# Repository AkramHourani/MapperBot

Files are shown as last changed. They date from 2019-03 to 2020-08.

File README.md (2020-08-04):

# MapperBot / iSCAN: 
SLAM Robot and Algorithm based on Matlab and Arduino

Robot name: MapperBot  
Algorithm name: iSCAN  

Video link to the robot: https://www.youtube.com/watch?v=dXMMgDs58lA

For detailed infromaiton about the SLAM algorithms based on particel filter:
Al-Hourani, A., Ristic, B. MapperBot/iSCAN: open-source integrated robotic platform and algorithm for 2D mapping. Int J Intell Robot Appl 4, 44–56 (2020). https://doi.org/10.1007/s41315-020-00118-3

# iSCAN Algorithm
For details please read the full paper describing the algorithm and the robot’s function.  
The project indludes three sample LIDAR row data collected using MapperBot, to run the demo: **\iSCAN\main.m**  
You can try the different measurements by uncommenting the relevant file inside: \iSCAN\main.m  
You can change the algorithm parameters under in the file: \iSCAN\Parameters.m

# MapperBot
The source files for the Arduino are inside the folder: \ArduinoSourceCode  
Hardware layout and photo inside the folder: \HardwareDesign
The file: \Robot Control\A01_MapperBot_Mouse.m will allow you to control MapperBot using a mouse from Matlab environment.

The project is created/developed by Dr Akram Al-Hourani (2019)  
Condition of use: please cite the paper

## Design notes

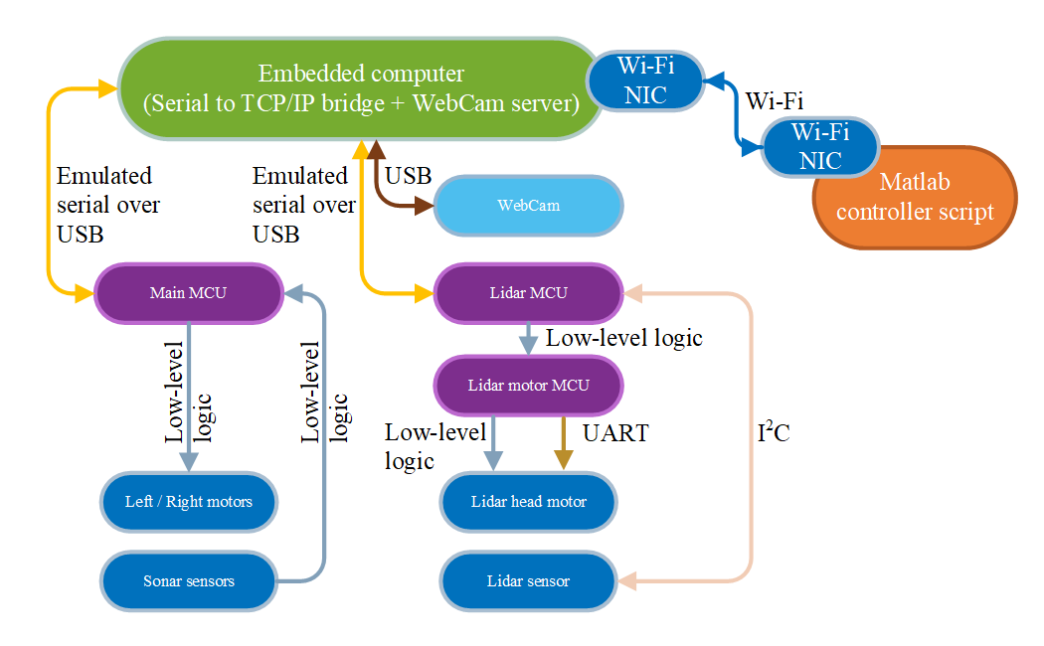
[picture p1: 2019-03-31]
HardwareDesign/HarwareDiagram.png

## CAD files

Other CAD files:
CAD Designs/Alignment_Tong.ipt
CAD Designs/ArduinoDue.ipt
CAD Designs/Battery.ipt
CAD Designs/BatteryCover.ipt
CAD Designs/Bearing.ipt
CAD Designs/Belt.ipt
CAD Designs/Cover.ipt
CAD Designs/HeadStepper.ipt
CAD Designs/LIDAR.ipt
CAD Designs/LIDARHolder.ipt
CAD Designs/LIDARLite.ipt
CAD Designs/LIDARNeck.ipt
CAD Designs/Logic Reg.ipt
CAD Designs/Main Body.ipt
CAD Designs/MapperBot2.iam
CAD Designs/MotorClamp.ipt
CAD Designs/MotorReg.ipt
CAD Designs/RaspberryPi.ipt
CAD Designs/Sonar.ipt
CAD Designs/StepperMotor.ipt
CAD Designs/WheelCore.ipt
CAD Designs/WheelRubber.ipt

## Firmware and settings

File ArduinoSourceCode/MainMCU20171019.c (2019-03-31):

#include <AccelStepper.h> // library of the stepper motor
#include <MultiStepper.h>   // For coordinated movments

#define motorPin_L_En   48 // Enable Pin
#define motorPin_L_Dir  50 // Direction Pin
#define motorPin_L_Step 52 // Step Pin

#define motorPin_R_En   42 // Enable Pin
#define motorPin_R_Dir  44 //  Right Motor
#define motorPin_R_Step 46 // 
#define  DRIVER  1

#define DefaultSpeed 1000
#define HoldMillis 250

#define MS1R 22 // Motor step devider select pins (Right Motor)
#define MS2R 24 // Motor step devider select pins (Right Motor)
#define MS3R 26 // Motor step devider select pins (Right Motor)

#define MS1L 23 // Motor step devider select pins (Left Motor)
#define MS2L 25 // Motor step devider select pins (Left Motor)
#define MS3L 27 // Motor step devider select pins (Left Motor)

#define RST_LIDAR_Head 53 // Reset pin of the LIDAR head
#define RST_LIDAR_Motor 51 // Reset pin of the LIDAR stepper motor



/****************** Objects ********************************/
AccelStepper L_Motor(DRIVER, motorPin_L_Step, motorPin_L_Dir); //For NEMA17 Motors (step, direction)
AccelStepper R_Motor(DRIVER, motorPin_R_Step, motorPin_R_Dir);
MultiStepper MotorSet;
/***********************************************************/

/**************** Global variables *************************/
long positions[2];     // This will hold the target position for simultinuous running for two stepper motors
int StepsCounterL;     // Holding the actual stepps that the motor drove, this will be reported back to MATLAB
int StepsCounterR;
short int Buffer_index = 0;
char inData[52];       //Serial data buffer
char Command[52];      //The command received from serial port
unsigned long StopMillis = 0; // The millis at which the motor stops
/**********************************************************/


void setup() {  //MotorSet.addStepper(L_Motor);

  Serial.begin(115200);
  digitalWrite(RST_LIDAR_Head, HIGH);
  digitalWrite(RST_LIDAR_Motor, HIGH);
  pinMode(RST_LIDAR_Head, OUTPUT);
  pinMode(RST_LIDAR_Motor, OUTPUT);
  
  pinMode(motorPin_R_En, OUTPUT);
  pinMode(motorPin_L_En, OUTPUT);

  pinMode(MS1R, OUTPUT);
  pinMode(MS2R, OUTPUT);
  pinMode(MS3R, OUTPUT);

  pinMode(MS1L, OUTPUT);
  pinMode(MS2L, OUTPUT);
  pinMode(MS3L, OUTPUT);

  //set motor step devider
  digitalWrite(MS1R, LOW);
  digitalWrite(MS2R, HIGH);
  digitalWrite(MS3R, LOW);
 
  digitalWrite(MS1L, LOW);
  digitalWrite(MS2L, HIGH);
  digitalWrite(MS3L, LOW);


  L_Motor.setMaxSpeed(DefaultSpeed);
  L_Motor.setAcceleration(DefaultSpeed * 30);
  R_Motor.setMaxSpeed(DefaultSpeed);
  R_Motor.setAcceleration(DefaultSpeed * 30);

  MotorSet.addStepper(L_Motor);
  MotorSet.addStepper(R_Motor);

  //positions[0] = 1000;
  //positions[1] = 1000;
  //MotorSet.moveTo(positions);
  //MotorSet.runSpeedToPosition(); // Blocks until all are in position

  Serial.println("MapperBot V1.0");
  Serial.println("akram.hourani");
  Serial.println("@rmit.edu.au");
  Serial.println("20170813");
  Serial.println("");
  Serial.println("Command format XLLLLXRRRRDDDDD#");
  Serial.println("X:    +,-       (forward, backward)");
  Serial.println("L:    0000-4000   (left motor speed)");
  Serial.println("R:    0000-4000   (Right motor speed)");
  Serial.println("DDD:  0-99999 (Counter destination)");
  Serial.println("D# Disarm motors");
  Serial.println("R# Reset LIDAR Head");
  
  
  Serial.println("Motors check");


  // Motor check rotine
  MotorCheckRoutine();



  Serial.println("Ready !!");
}

void loop() {

  if (Serial.available() > 0) {
    inData[Buffer_index] = Serial.read();
    Buffer_index++;

    //When a commdan is ready execute the following
    if (inData[Buffer_index - 2] == '#' && Buffer_index > 1)  {
      // Serial.print("Debug 1 ");
      memset(Command, 0, sizeof(Command)); // Clear recieved buffer
      strncpy(Command, inData, Buffer_index); // Save the command
      Buffer_index = 0; // reset the buffer pointer
      //Serial.println(Command);
      Serial.print(Command);

      Execute_Command();
    }

  }


  if ( (millis()-StopMillis ) > HoldMillis) // Disable the motors after a period of HoldMillis
  {
    digitalWrite(motorPin_L_En, HIGH);
    digitalWrite(motorPin_R_En, HIGH);
  }

}

/************************************************************************************/
// This is the main function of montion and reporting
void moveToFunc(int SpeedLN, int SpeedRN, int SteppsLN) {
  digitalWrite(motorPin_L_En, LOW);
  digitalWrite(motorPin_R_En, LOW);

  // Reset poistion
  L_Motor.setCurrentPosition(0);
  R_Motor.setCurrentPosition(0);

  L_Motor.setMaxSpeed(abs(SpeedLN));
  R_Motor.setMaxSpeed(abs(SpeedRN));

  if (SpeedLN < 0)   positions[0] = -SteppsLN ;
  else   positions[0] = SteppsLN ;
  if (SpeedRN < 0)  positions[1] = -SteppsLN ;
  else   positions[1] = SteppsLN ;
  //MotorSet.moveTo(positions);
  L_Motor.moveTo(positions[0]);
  R_Motor.moveTo(positions[1]);

   MotorSet.moveTo(positions);
   MotorSet.runSpeedToPosition(); // Blocks until all are in position

  // This will run both motor simultinuously. The processor is blocked untill the command is executed.
 /* while (L_Motor.distanceToGo() != 0 || R_Motor.distanceToGo() != 0)
  {
    L_Motor.run();
    R_Motor.run();
    //L_Motor.runSpeedToPosition();
    //R_Motor.runSpeedToPosition();
  }*/


  StepsCounterL = L_Motor.currentPosition();
  StepsCounterR = -R_Motor.currentPosition();

  StopMillis = millis();


}
/************************************************************************************/


/************************************************************************************/
void Execute_Command() {

  bool error = 0;

  if (Command[0] == 'D') // disarm the motors
  {
    digitalWrite(motorPin_L_En, HIGH);
    digitalWrite(motorPin_R_En, HIGH);
  }

 else if (Command[0] == 'R') // Send a reset signal to the LIADR head
  {

  digitalWrite(RST_LIDAR_Head, LOW);
  digitalWrite(RST_LIDAR_Motor, LOW);
  delay(200);
  digitalWrite(RST_LIDAR_Head, HIGH);
  digitalWrite(RST_LIDAR_Motor, HIGH);
  }

  else // Motion Command
  {
    char SteppsLNc[52];
    memset(SteppsLNc, 0, sizeof(SteppsLNc));

    char SpeedLNc[48];
    memset(SpeedLNc, 0, sizeof(SpeedLNc));

    char SpeedRNc[48];
    memset(SpeedRNc, 0, sizeof(SpeedRNc));

    int SteppsLN;
    int SpeedLN;
    int SpeedRN;

    for (int i = 0 ; i < 4; i++) SpeedLNc[i] = Command[i + 1]; //copy  digits 1,2,3,4 left speed
    for (int i = 0 ; i < 4; i++) SpeedRNc[i] = Command[i + 6]; //copy  digits 6,7,8,9 right speed
    for (int i = 0 ; i < 5; i++) SteppsLNc[i] = Command[i + 10]; //copy digits 10,11,12,13,14 Destination counter


    if (Command[0] == '+')   SpeedLN =   atoi(SpeedLNc); // Moving Forward
    else if (Command[0] == '-')    SpeedLN = - atoi(SpeedLNc);// Moving Forward}
    else error = 1;


    if (Command[5] == '+')   SpeedRN =   -atoi(SpeedRNc);  // Moving Forward
    else if (Command[5] == '-')   SpeedRN =  atoi(SpeedRNc);  // Moving Forward


    else    error = 1;


    SteppsLN =   atoi(SteppsLNc); // Moving Forward

    if (error)
    {
      Serial.println("Invalid command !");
      Serial.flush(); //flush the serial buffer
      // reset the buffer data and buffer index
      memset(inData, 0, sizeof(inData));
      Buffer_index = 0;

    }
    else {

      moveToFunc(SpeedLN, SpeedRN, SteppsLN);
      Serial.println("Ok");

    }
  }

}


void MotorCheckRoutine(void)
{
  //Enable the motors
  digitalWrite(motorPin_L_En, LOW);
  digitalWrite(motorPin_R_En, LOW);

  positions[0] = 200;
  positions[1] = 200;

  L_Motor.moveTo(positions[0]);
  R_Motor.moveTo(positions[1]);

  while (L_Motor.distanceToGo() != 0 || R_Motor.distanceToGo() != 0)
  {
    L_Motor.run();
    R_Motor.run();
  }

  delay(200);
  positions[0] = -200;
  positions[1] = -200;

  L_Motor.moveTo(positions[0]);
  R_Motor.moveTo(positions[1]);
  while (L_Motor.distanceToGo() != 0 || R_Motor.distanceToGo() != 0)
  {
    L_Motor.run();
    R_Motor.run();
  }
delay(200);
  positions[0] = 0;
  positions[1] = 0;

  L_Motor.moveTo(positions[0]);
  R_Motor.moveTo(positions[1]);
  while (L_Motor.distanceToGo() != 0 || R_Motor.distanceToGo() != 0)
  {
    L_Motor.run();
    R_Motor.run();
  }

StopMillis = millis();
}

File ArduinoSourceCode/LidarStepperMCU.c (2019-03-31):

#include <AccelStepper.h> // library of the stepper motor
#include <Wire.h>         //I2C


#define motorPin_Dir  11 // Direction Pin
#define motorPin_Step 12 // Step Pin
#define MS1 8//Step devider bit1
#define MS2 9//Step devider bit2
#define MS3 10//Step devider bit3
#define TPP 7// Trigger Pin poisitve side (CCW)
#define TPN 6// Trigger Pin negative side (CW)
#define READY 5// Rotation READY Pin
#define motorPin_En 4 // Motor enable pin
#define LimitSig  2 // Optical limit swtich Signal line


//#define FullRot 1994 // number of stepps for full rotation
#define FullRot 3988 // number of stepps for full rotation
#define MaxSpeed 2500
#define DRIVER  1 // This is for NEMA 17 stepper motor

#define HoldMillis 250 // The amount of millis to hold the motors on
/****************** Objects ********************************/
AccelStepper LIDARMotor(DRIVER, motorPin_Step, motorPin_Dir); //For NEMA17 Motors (step, direction)
//LIDARLite    MyLIDAR;

/**************** Global variables *************************/
short int Buffer_index = 0;
char inData[52];       //Serial data buffer
char Command[52];      //The command received from serial port
unsigned int dist;
unsigned long StopMillis = 0; // The millis at which the motor stops
/**********************************************************/

void setup() {
  Serial.begin(4800);

  digitalWrite(LimitSig, LOW); // pulldown resistor
  pinMode(LimitSig, INPUT);

  digitalWrite(MS1, LOW); // pulldown resistor

  pinMode(MS1, OUTPUT);
  pinMode(MS2, OUTPUT);
  pinMode(MS3, OUTPUT);
  pinMode(motorPin_En, OUTPUT);

  pinMode(TPP, INPUT_PULLUP);
  pinMode(TPN, INPUT_PULLUP);
  pinMode(READY, OUTPUT);



  // The below settings will give 1/8 stepp
  digitalWrite(MS1, HIGH);
  digitalWrite(MS2, HIGH);
  digitalWrite(MS3, LOW);

  LIDARMotor.setMaxSpeed(MaxSpeed);
  LIDARMotor.setAcceleration(MaxSpeed * 700);

  Serial.println("Motor Driver V1.0");
  Serial.println("akram.hourani@rmit.edu.au");
  Serial.println("Firmware: 20170828");
  Serial.println("");
  Serial.println("Command format XSSSDDDDD#");
  Serial.println("X:      +,-         (CCW, CW)");
  Serial.println("SSSS:   0000-2000     (Speed)");
  Serial.println("DDDDD:  00000-99999 (Counter destination)");
  Serial.println("Motors check started...");
  RST_Rotine();

  digitalWrite(READY, HIGH); // This means the system is ready
}

void loop() {


  //****** This is to monitor the serial Port **********//
  if (Serial.available() > 0) {
    inData[Buffer_index] = Serial.read();
    Buffer_index++;

    //When a commdan is ready execute the following
    if (inData[Buffer_index - 1] == '#' && Buffer_index > 1)  {
      // Serial.print("Debug 1 ");
      memset(Command, 0, sizeof(Command)); // Clear recieved buffer
      strncpy(Command, inData, Buffer_index); // Save the command
      Buffer_index = 0; // reset the buffer pointer
      //Serial.println(Command);
      Serial.println(Command);

      Execute_Command();
    }

  }

  //****** This is to monitor the trigger pins **********//
  if (!digitalRead(TPP)) {
    while (!digitalRead(TPP)); // Wait untill the line goes high again
    digitalWrite(READY, LOW); // This mean that the motor driver is busy
    moveToFunc(MaxSpeed, FullRot);
    digitalWrite(READY, HIGH); // This mean the rotation is done

  }

  if (!digitalRead(TPN)) {
    while (!digitalRead(TPN)); // Wait untill the line goes high again
    digitalWrite(READY, LOW); // This mean that the motor driver is busy
    moveToFunc(MaxSpeed, -FullRot);
    digitalWrite(READY, HIGH); // This mean the rotation is done
  }

  // This will diable the motors to save energy
  if ( (millis() - StopMillis ) > HoldMillis) // Disable the motors after a period of HoldMillis
  {
    digitalWrite(motorPin_En, HIGH);
  }


}

/**** Motor check rotine ****/

void RST_Rotine() {
  bool SucessFlag = false; // Reset the sucess falg to 0
  

  moveToFunc(MaxSpeed / 2, -int(FullRot / 30));

  digitalWrite(motorPin_En, LOW);
  LIDARMotor.setCurrentPosition(0);
  LIDARMotor.moveTo(FullRot * 1.1); // Move 10% more than a full rotation
  LIDARMotor.setSpeed(MaxSpeed);
  //LIDARMotor.runToPosition();
  while (LIDARMotor.distanceToGo() != 0)
  {
    LIDARMotor.runSpeedToPosition(); // No acceleration
    if (digitalRead(LimitSig))
    {
      SucessFlag = true; // Set the sucess falg to 1
      break; // exite the loop when reaching the zero position

    }
  }

  if (SucessFlag)
  {
    Serial.println("Reset succeeded!");
    Serial.println("Ready to receive commands");
  }
  else
  {
    Serial.println("Reset failed! check the limit switch !!!!");
  }

}



/************************************************************************************/
// This is the main function of montion and reporting
void moveToFunc(int SpeedN, long SteppsN) {
  digitalWrite(motorPin_En, LOW);
  int positions;
  // Reset poistion
  LIDARMotor.setCurrentPosition(0);

  if (SpeedN < 0)   positions = -SteppsN ;
  else   positions = SteppsN ;

  LIDARMotor.moveTo(positions); // this relative move
  //LIDARMotor.setMaxSpeed(abs(SpeedN));
  LIDARMotor.setSpeed(abs(SpeedN));
  //LIDARMotor.runToPosition();
  while (LIDARMotor.distanceToGo() != 0)
  {
    LIDARMotor.runSpeedToPosition(); // No acceleration
  }

  StopMillis = millis();
}
/************************************************************************************/




/*******************************************************************************/
void Execute_Command() {

  bool error = 0;


  if (Command[0] == 'R') // Reset Command --> reset to zero position
  {
    RST_Rotine();
  }

  else // Motion Command
  {
    char SteppsNc[52];
    memset(SteppsNc, 0, sizeof(SteppsNc));

    char SpeedNc[48];
    memset(SpeedNc, 0, sizeof(SpeedNc));

    long SteppsN;
    long SpeedN;

    for (int i = 0 ; i < 4; i++) SpeedNc[i]  = Command[i + 1];  //copy  digits 1,2,3,4 left speed
    for (int i = 0 ; i < 5; i++) SteppsNc[i] = Command[i + 1 + 4]; //copy  digits 5,6,7,8,9 right speed


    if (Command[0] == '+')   SpeedN =   atoi(SpeedNc); // Moving Forward
    else if (Command[0] == '-')    SpeedN = - atoi(SpeedNc);// Moving Forward}
    else error = 1;

    SteppsN =   atol(SteppsNc); // Moving Forward

    if (error)
    {
      Serial.println("Invalid command !");
      // reset the buffer data and buffer index
      memset(inData, 0, sizeof(inData));
      Buffer_index = 0;
    }
    else {
      moveToFunc(SpeedN, SteppsN);

    }
  }

}
